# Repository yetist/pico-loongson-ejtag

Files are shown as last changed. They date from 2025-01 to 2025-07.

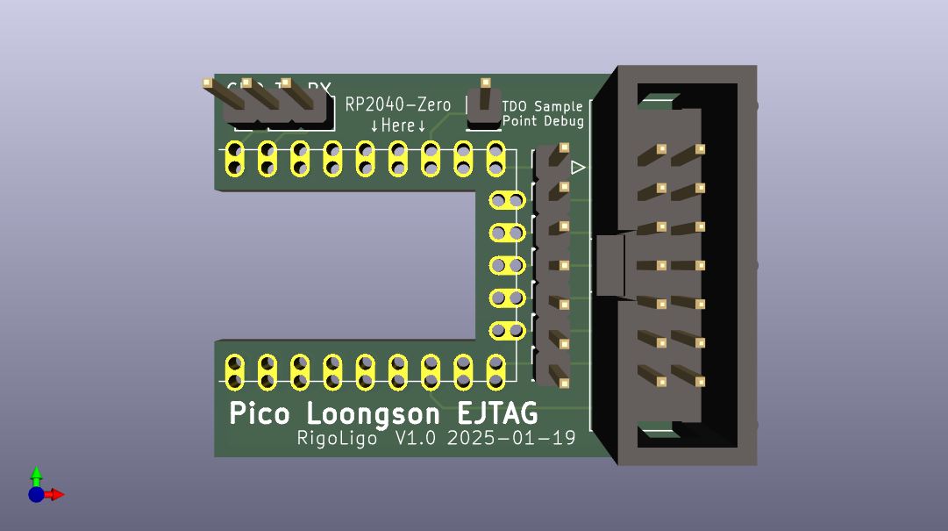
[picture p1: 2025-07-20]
hardware/lsejtag-rp2040zero-front.png

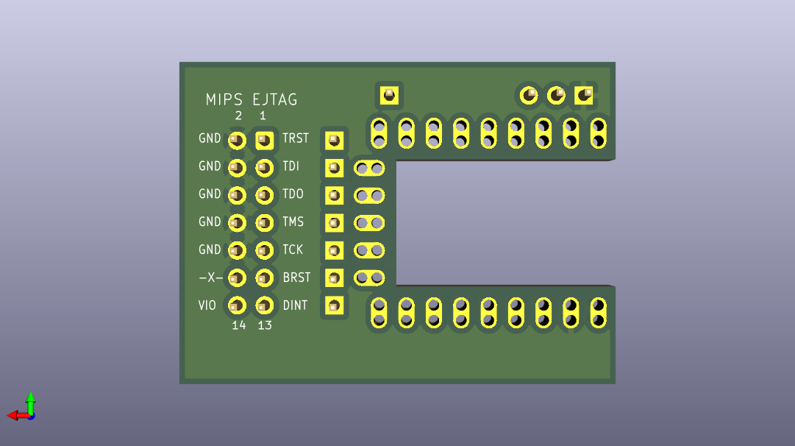
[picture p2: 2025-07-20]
hardware/lsejtag-rp2040zero-background.png

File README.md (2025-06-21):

# Pico Loongson EJTAG

[ENGLISH](README.en.md)

降成本版新款点这里 >> [CH32 Loongson EJTAG](https://github.com/RigoLigoRLC/ch32-loongson-ejtag)

欢迎加入！本项目专为龙芯嵌入式开发者爱好者打造，旨在重新实现龙芯官方EJTAG仿真器的核心功能，力求实现硬件功能完全对标且上位机软件兼容互通。

作为龙芯生态的共建者，我们深知龙芯3A6000等桌面级处理器性能比较亮眼，但其整机体积大、价格门槛高、与海外顶尖产品尚存差距的现状，让不少开发者望而却步（包括笔者本人）。而2K0300开发板的问世彻底改变了这一局面——这颗SoC不仅拥有媲美（超越）iMX6ULL等主流芯片的CoreMark性能，支持跑Linux/裸机，更以价格（百元级开发板）和小巧体积，为开发者打开了低成本进入LoongArch世界的通道。

然而，对于专注于裸机开发的嵌入式开发者而言，现有生态仍存在痛点：虽然2K0300可运行裸机程序，但官方调试工具高昂的售价成为了拦路虎。长期以来，龙芯的主要业务集中在桌面领域，对嵌入式生态投入有限（2K0300至今仅有第三方提供的残缺SDK，其IDE更是近乎讽刺地仅支持Windows平台）。我们希望通过这个项目证明：嵌入式开发者完全有能力为LoongArch的嵌入式开放生态开辟道路。

当前，固件基于逆向工程成果，主要参考对象为搭载20210129版本FPGA固件的官方调试工具和`la_dbg_tool_usb.exe`工具，并基于此独立实现了设备与上位机的通信协议、JTAG驱动。

## 功能完整度

当前版本还未完整实现所有命令的执行，会导致部分调试功能无法使用：

- 0xe，0xf：快速读内存指令

  将导致批量读取内存不可用

部分功能未完整验证，可能在部分机器上工作异常：

- 0xc，0xd：快速写内存指令

  未在 2K0300 以外的机器上测试，多核心处理器的适应性不明。仅在 2K0300 上测试了 SPI Flash 烧写功能。

## 实现方案

本固件基于树莓派RP2040-Zero开发板（成本极低，轻松复刻），具体引脚定义如下：

| RP2040 GPIO编号 | JTAG信号  | 备注 |
|---|---|-----|
| 8 | #TRST | |
| 9 | TDI | |
| 10 | TDO | |
| 11 | TMS | |
| 12 | TCK | |
| 13 | #BRST | |
| 14 | #DINT | |
| 26 | VIO | 模拟引脚 |

板载WS2812（GPIO16控制）作为状态指示灯，GPIO0/1上的UART0接口可输出开发调试信息。

- `src/lsejtag`与`inc/lsejtag`目录封装了与平台无关的核心逻辑（内部称其为`LS-EJTAG`协议栈，但并没有独立发布），负责处理上位机指令解析
- `src/ejtag_impl.c`包含硬件平台相关代码，移植至其他主控芯片时需重新实现

我们正在酝酿基于HPM5301主控的升级方案（硬件设计采用OSL-W-2.0协议开源，固件遵循GPL-3.0协议），重点是利用它的高速USB以图加快速度，敬请期待！

# 构建指南

我个人因为并不想安装体积比较大的SDK安装包，基于Windows环境手搓了构建流程，请按以下步骤配置开发环境：

## picotool安装
请将`picotool`完整安装至`C:\Program Files\CMake\picotool\`目录（内含CMake目标文件等必要组件）。`pioasm`工具也需同步安装。

**替代方案**：将安装目录路径添加至`CMAKE_PREFIX_PATH`环境变量，具体方式可依个人偏好选择。

## 环境配置
- `PICO_SDK_BASE`：设置为pico-sdk仓库的本地克隆路径（直接指向仓库根目录）
- `PICO_SDK_COMPILER_PATH`：指向MCU编译器所在目录（需包含`arm-none-eabi-gcc.exe`等可执行文件）

## VSCode编译流程
1. 通过Workspace Settings配置上述环境变量
2. 启动构建时选择"ARM GCC (Pico)"工具链
3. 正常情况下即可完成编译，若遇异常...祝君调试愉快

## clangd适配
因clangd/LLVM的设计缺陷（详见clangd/clangd#2289），需在clangd参数中添加：`--query-driver=.../your/gnu/toolchain/bin/arm-none-eabi-*.exe`以强制clangd识别GNU工具链路径（否则会误判为LLVM工具链导致头文件搜索失败）

# 许可

本项目除引用了其他项目有明确版权标识的文件之外，其他的代码均以 GPL-3.0-only 许可证发布。

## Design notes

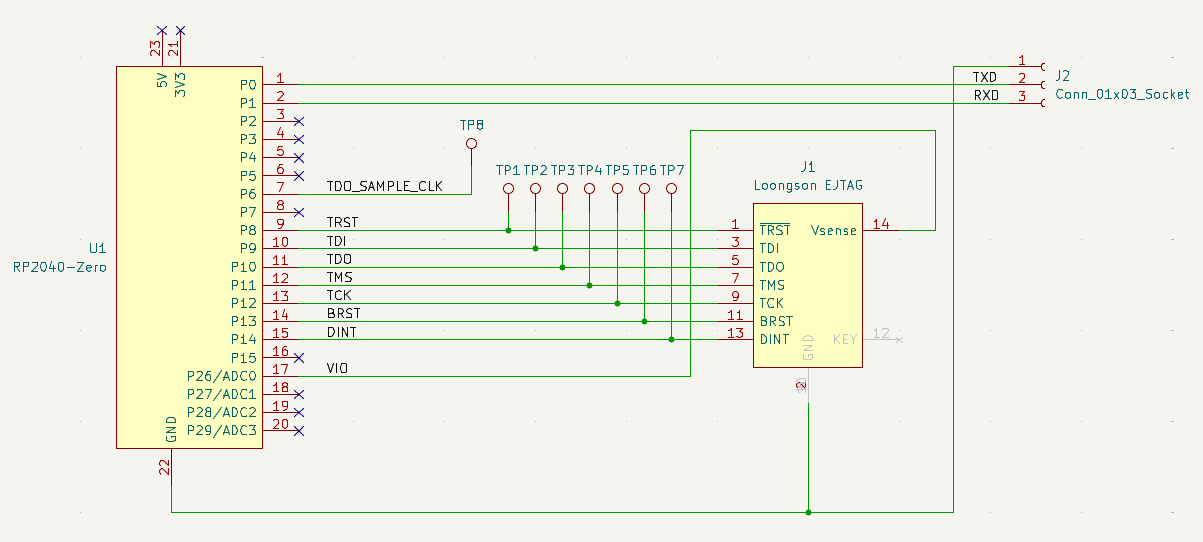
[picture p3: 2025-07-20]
hardware/lsejtag-rp2040zero-pcb.png

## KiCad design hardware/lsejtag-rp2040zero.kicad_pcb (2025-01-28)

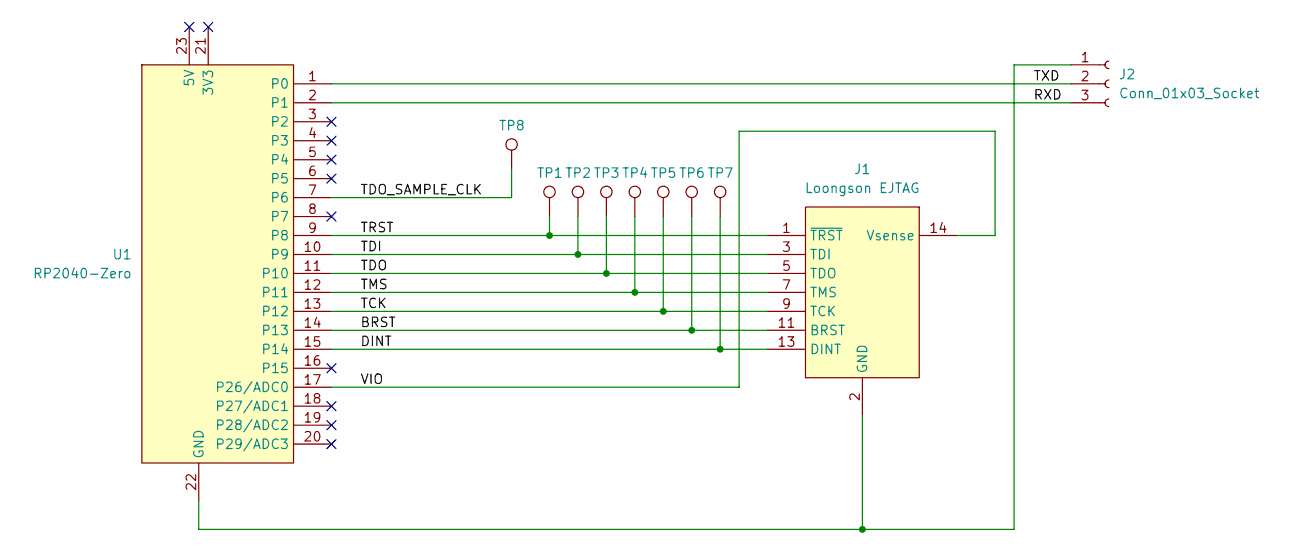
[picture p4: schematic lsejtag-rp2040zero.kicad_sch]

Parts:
J1: Loongson EJTAG; IDC-Header_2x07_P2.54mm_Vertical
J2: Conn_01x03_Socket; PinHeader_1x03_P2.54mm_Vertical
TP1, TP2, TP3, TP4, TP5, TP6, TP7, TP8: TestPoint; PinHeader_1x01_P2.54mm_Vertical
U1: RP2040-Zero

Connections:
/BRST: J1.11 (BRST), TP6.1, U1.14 (P13)
/DINT: J1.13 (DINT), TP7.1, U1.15 (P14)
/RXD: J2.3, U1.2 (P1)
/TCK: J1.9 (TCK), TP5.1, U1.13 (P12)
/TDI: J1.3 (TDI), TP2.1, U1.10 (P9)
/TDO: J1.5 (TDO), TP3.1, U1.11 (P10)
/TDO_SAMPLE_CLK: TP8.1, U1.7 (P6)
/TMS: J1.7 (TMS), TP4.1, U1.12 (P11)
/TRST: J1.1 (~TRST), TP1.1, U1.9 (P8)
/TXD: J2.2, U1.1 (P0)
/VIO: J1.14 (Vsense), U1.17 (P26/ADC0)
GND: J1.2 (GND), J1.4 (GND), J1.6 (GND), J1.8 (GND), J1.10 (GND), J2.1, U1.22 (GND)

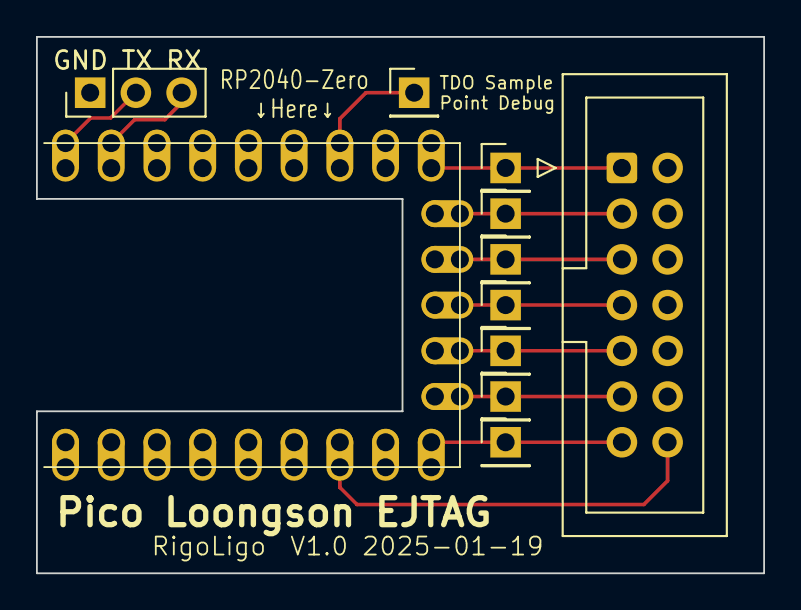
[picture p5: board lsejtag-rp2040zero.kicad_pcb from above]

Board: 2 copper layers, 40.4 x 29.8 mm, 11 parts (0 on the bottom side), 12 nets.

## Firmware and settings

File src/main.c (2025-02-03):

#include <pico/stdlib.h>
#include <hardware/uart.h>
#include <hardware/gpio.h>
#include <hardware/pio.h>
#include <hardware/dma.h>
#include <tusb.h>
#include <string.h>

#include "shell_port.h"
#include "lsejtag/lsejtag.h"
#include "config.h"
#include "ejtag.h"

#include "ejtag.pio.h"
#include "ws2812.pio.h"

lsejtag_ctx lsejtag_lib_ctx;
ejtag_impl_ctx ejtag_ctx;
Shell shell;
char shellBuffer[512];

void init_hardware();
void init_software();
void init_reset_tap_via_tms();
void init_print_clock();

void led_task();

int main() {
    init_hardware();
    init_software();
    init_reset_tap_via_tms();
    // init_print_clock();

    while (1) {
        tud_task();
        // shellTask(&shell);
        led_task();

        switch (lsejtag_dispatch(&lsejtag_lib_ctx)) {
        case dpr_execute:
            lsejtag_execute(&lsejtag_lib_ctx);
            break;
        case dpr_incomplete:
            break;
        case dpr_flush_tdo:
            lsejtag_flush_tdo(&lsejtag_lib_ctx);
            break;
        case dpr_run_jtag:
            lsejtag_run_jtag(&lsejtag_lib_ctx);
            break;
        case dpr_too_long:
            panic("LSEJTAG command too long");
        case dpr_unknown_cmd:
            break;
        case dpr_corrupt_state:
            printf("!!!!!! dpr_corrput_state !!!!!!\n");
            printf("cmd buf dump:\n");
            // dump_binary_to_console(ctx->buffered_cmd, sizeof(ctx->buffered_cmd));
            printf("buffered_length: %d\r", (int)lsejtag_lib_ctx.buffered_length);
            printf("wait_payload_size: %d\n", (int)lsejtag_lib_ctx.cmd_buf_wait_payload_size);
            printf("state: %d\n",lsejtag_lib_ctx.cmd_buf_state);
            panic("LSEJTAG corrupt state");
        case dpr_clean:
          break;
        }
    }
}

//==============================================================================
// Util
//==============================================================================

static inline uint32_t ws2812_rgb_u32(uint8_t r, uint8_t g, uint8_t b) {
    return
            ((uint32_t) (r) << 8) |
            ((uint32_t) (g) << 16) |
            (uint32_t) (b);
}

void isr_hardfault() {
    *ejtag_ctx.ws2812_write_addr = 0x10201000;
    stdio_puts_raw("!! HardFault !!\r\n");
    while (1);
}

//==============================================================================
// Other tasks
//==============================================================================

void led_task() {
    // LED illumination logic
    if (ejtag_ctx.led_turn_on) {
        ejtag_ctx.led_turn_on = 0;
        ejtag_ctx.led_timer_us = time_us_32();
        *ejtag_ctx.ws2812_write_addr = 0x10200000;
        return;
    }

    if (ejtag_ctx.led_timer_us == 0) {
        return;
    }

    // 300ms
    if (time_us_32() - ejtag_ctx.led_timer_us >= 300000) {
        *ejtag_ctx.ws2812_write_addr = 0x00200000;
        ejtag_ctx.led_timer_us = 0;
    }
}

//==============================================================================
// Initialization
//==============================================================================

void init_uart() {
    stdio_uart_init_full(uart0, 115200, 0, 1);

    printf("Pico Loongson EJTAG - By RigoLigo, FW Version " FIRMWARE_VERSION_STR "\n");
    printf("The Loongson EJTAG Probe reimplementation on RP2040.\n");
}

void init_gpio() {
    gpio_init(EJTAG_PIN_TRST);
    gpio_init(EJTAG_PIN_BRST);
    gpio_init(EJTAG_PIN_DINT);
    
    gpio_set_dir(EJTAG_PIN_TRST, true);
    gpio_set_dir(EJTAG_PIN_BRST, true);
    gpio_set_dir(EJTAG_PIN_DINT, true);

    gpio_set_pulls(EJTAG_PIN_TRST, true, false);
    gpio_set_pulls(EJTAG_PIN_BRST, true, false);
    gpio_set_pulls(EJTAG_PIN_DINT, true, false);

    gpio_put(EJTAG_PIN_TRST, true);
    gpio_put(EJTAG_PIN_BRST, true);
    gpio_put(EJTAG_PIN_DINT, true);
}

void init_pio() {
    pio_sm_config smcfg = pio_get_default_sm_config();
    static const char panic_text[] = "%s PIO SM allocation failed. This should not happen.";

    // TDI/TMS SM program
    if (pio_add_program_at_offset(pio0, &ejtag_tdi_program, SM_PC_TDI) < 0) {
        panic(panic_text, "TDI");
    }
    if (pio_add_program_at_offset(pio0, &ejtag_tms_program, SM_PC_TMS) < 0) {
        panic(panic_text, "TMS");
    }
    if (pio_add_program_at_offset(pio0, &ejtag_tdo_program, SM_PC_TDO) < 0) {
        panic(panic_text, "TDO");
    }
    if (pio_add_program_at_offset(pio0, &ws2812_program, SM_PC_WS2812) < 0) {
        panic(panic_text, "WS2812");
    }

    // EJTAG GPIO alternative function selection
    pio_gpio_init(pio0, EJTAG_PIN_TDI);
    pio_gpio_init(pio0, EJTAG_PIN_TDO);
    pio_gpio_init(pio0, EJTAG_PIN_TCK);
    pio_gpio_init(pio0, EJTAG_PIN_TMS);
    pio_gpio_init(pio0, EJTAG_PIN_BRST); // TODO:REMOVE
    pio_gpio_init(pio0, EJTAG_PIN_TDO_SAMPLE_TIME);

    // TDI SM config
    pio_sm_set_consecutive_pindirs(pio0, SM_TDI, EJTAG_PIN_TDI, 1, true);
    pio_sm_set_consecutive_pindirs(pio0, SM_TDI, EJTAG_PIN_TCK, 1, true);
    pio_sm_set_consecutive_pindirs(pio0, SM_TDI, EJTAG_PIN_BRST, 1, true);
    sm_config_set_fifo_join(&smcfg, PIO_FIFO_JOIN_TX);
    sm_config_set_out_pins(&smcfg, EJTAG_PIN_TDI, 1);
    sm_config_set_out_shift(&smcfg, true, false, 0);
    sm_config_set_sideset_pins(&smcfg, EJTAG_PIN_BRST); // TODO:REMOVE
    sm_config_set_sideset(&smcfg, 1, false, false); // TODO:REMOVE
    sm_config_set_wrap(&smcfg, ejtag_tdi_wrap_target + SM_PC_TDI, ejtag_tdi_wrap + SM_PC_TDI);
    sm_config_set_clkdiv(&smcfg, 6.f);
    pio_sm_init(pio0, SM_TDI, SM_PC_TDI, &smcfg);
    ejtag_ctx.tdi_write_addr = &pio0->txf[SM_TDI];

    // TDI SM IRQ (IRQ bit 0, this is for TDI&TMS completion handler since they are in sync)
    irq_set_exclusive_handler(PIO0_IRQ_0, isr_pio0_irq0);
    pio_set_irq0_source_enabled(pio0, pis_interrupt0, true);
    irq_set_enabled(PIO0_IRQ_0, true);

    // TMS SM config
    pio_sm_set_consecutive_pindirs(pio0, SM_TMS, EJTAG_PIN_TMS, 1, true);
    sm_config_set_out_pins(&smcfg, EJTAG_PIN_TMS, 1);
    sm_config_set_sideset_pins(&smcfg, EJTAG_PIN_TCK);
    sm_config_set_sideset(&smcfg, 1, false, false);
    sm_config_set_wrap(&smcfg, ejtag_tms_wrap_target + SM_PC_TMS, ejtag_tms_wrap + SM_PC_TMS);
    pio_sm_init(pio0, SM_TMS, SM_PC_TMS, &smcfg);
    ejtag_ctx.tms_write_addr = &pio0->txf[SM_TMS];

    // TDO SM (PIO0, SM2) config
    pio_sm_set_consecutive_pindirs(pio0, SM_TDO, EJTAG_PIN_TDO, 1, false);
    pio_sm_set_consecutive_pindirs(pio0, SM_TDO, EJTAG_PIN_TDO_SAMPLE_TIME, 1, true);
    sm_config_set_fifo_join(&smcfg, PIO_FIFO_JOIN_NONE);
    sm_config_set_sideset_pins(&smcfg, EJTAG_PIN_TDO_SAMPLE_TIME);
    sm_config_set_in_pins(&smcfg, EJTAG_PIN_TDO);
    sm_config_set_wrap(&smcfg, ejtag_tdo_wrap_target + SM_PC_TDO, ejtag_tdo_wrap + SM_PC_TDO);
    pio_sm_init(pio0, SM_TDO, SM_PC_TDO, &smcfg);
    ejtag_ctx.tdo_write_addr = &pio0->txf[SM_TDO];
    ejtag_ctx.tdo_read_addr = &pio0->rxf[SM_TDO];

    // WS2812 SM (PIO0, SM3) config
    ws2812_program_init(pio0, SM_WS2812, SM_PC_WS2812, WS2812_PIN, 800000, false);
    ejtag_ctx.ws2812_write_addr = &pio0->txf[SM_WS2812];
}

void init_dma() {
    dma_channel_config cfg;

    ejtag_ctx.tdi_chan = dma_claim_unused_channel(true);
    cfg = dma_channel_get_default_config(ejtag_ctx.tdi_chan);
    channel_config_set_transfer_data_size(&cfg, DMA_SIZE_32);
    channel_config_set_read_increment(&cfg, true);
    channel_config_set_write_increment(&cfg, false);
    channel_config_set_dreq(&cfg, DREQ_PIO0_TX0 + SM_TDI);
    dma_channel_configure(ejtag_ctx.tdi_chan, &cfg, ejtag_ctx.tdi_write_addr, NULL, 0, false);

    ejtag_ctx.tms_chan = dma_claim_unused_channel(true);
    channel_config_set_dreq(&cfg, DREQ_PIO0_TX0 + SM_TMS);
    channel_config_set_chain_to(&cfg, ejtag_ctx.tms_chan);
    dma_channel_configure(ejtag_ctx.tms_chan, &cfg, ejtag_ctx.tms_write_addr, NULL, 0, false);

    ejtag_ctx.tdo_chan = dma_claim_unused_channel(true);
    channel_config_set_read_increment(&cfg, false);
    channel_config_set_write_increment(&cfg, true);
    channel_config_set_dreq(&cfg, DREQ_PIO0_RX0 + SM_TDO);
    channel_config_set_chain_to(&cfg, ejtag_ctx.tdo_chan);
    dma_channel_configure(ejtag_ctx.tdo_chan, &cfg, NULL, ejtag_ctx.tdo_read_addr, 0, false);

    ejtag_ctx.dma_start_mask_no_tdo = (1 << ejtag_ctx.tdi_chan) | (1 << ejtag_ctx.tms_chan);
    ejtag_ctx.dma_start_mask = (1 << ejtag_ctx.tdo_chan) | ejtag_ctx.dma_start_mask_no_tdo;

    // Interrupts
    dma_channel_set_irq0_enabled(ejtag_ctx.tdi_chan, true);
    dma_channel_set_irq0_enabled(ejtag_ctx.tms_chan, true);
    dma_channel_set_irq1_enabled(ejtag_ctx.tdo_chan, true);

    irq_set_exclusive_handler(DMA_IRQ_0, isr_dma_irq0);
    irq_set_exclusive_handler(DMA_IRQ_1, isr_dma_irq1);
    irq_set_enabled(DMA_IRQ_0, true);
    irq_set_enabled(DMA_IRQ_1, true);
}

void init_hardware() {
    init_uart();
    init_gpio();
    init_pio();
    init_dma();
}

void init_task_context() {
    // LED task
    ejtag_ctx.led_timer_us = 0;
    ejtag_ctx.led_turn_on = 0;
    // Make red LED illuminate
    *ejtag_ctx.ws2812_write_addr = 0x00200000;
}

void init_software() {
    lsejtag_init_ctx(&lsejtag_lib_ctx);
    tud_init(BOARD_TUD_RHPORT);
    init_task_context();

    // shell.write = shell_port_write_usb;
    // // shell.read = shell_port_read_usb;
    // shellInit(&shell, shellBuffer, sizeof(shellBuffer));
}

void init_reset_tap_via_tms() {
    *ejtag_ctx.tms_write_addr = 31;
    *ejtag_ctx.tms_write_addr = 0x0FFFFFFF;
    pio_set_sm_mask_enabled(pio0, SM_MASK_TDI_TMS, true);
    sleep_ms(5); // This is more than enough!
    pio_set_sm_mask_enabled(pio0, SM_MASK_JTAG, false);
}

void init_print_clock() {
    uint f_pll_sys = frequency_count_khz(CLOCKS_FC0_SRC_VALUE_PLL_SYS_CLKSRC_PRIMARY);
    uint f_pll_usb = frequency_count_khz(CLOCKS_FC0_SRC_VALUE_PLL_USB_CLKSRC_PRIMARY);
    uint f_rosc = frequency_count_khz(CLOCKS_FC0_SRC_VALUE_ROSC_CLKSRC);
    uint f_clk_sys = frequency_count_khz(CLOCKS_FC0_SRC_VALUE_CLK_SYS);
    uint f_clk_peri = frequency_count_khz(CLOCKS_FC0_SRC_VALUE_CLK_PERI);
    uint f_clk_usb = frequency_count_khz(CLOCKS_FC0_SRC_VALUE_CLK_USB);
    uint f_clk_adc = frequency_count_khz(CLOCKS_FC0_SRC_VALUE_CLK_ADC);

    puts("Clocks debug:");
    printf("pll_sys  = %dkHz\n", f_pll_sys);
    printf("pll_usb  = %dkHz\n", f_pll_usb);
    printf("rosc     = %dkHz\n", f_rosc);
    printf("clk_sys  = %dkHz\n", f_clk_sys);
    printf("clk_peri = %dkHz\n", f_clk_peri);
    printf("clk_usb  = %dkHz\n", f_clk_usb);
    printf("clk_adc  = %dkHz\n", f_clk_adc);
}

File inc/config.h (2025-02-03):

#pragma once

#define DISABLE_DBGPRINT

#ifndef FIRMWARE_VERSION_STR
#define FIRMWARE_VERSION_STR            "0.2.0"
#endif

#ifndef DISABLE_DBGPRINT
#define DbgPrint printf
#else
#define DbgPrint(...)
#endif

#define EJTAG_PIN_TRST                  8
#define EJTAG_PIN_TDI                   9
#define EJTAG_PIN_TDO                   10
#define EJTAG_PIN_TMS                   11
#define EJTAG_PIN_TCK                   12
#define EJTAG_PIN_BRST                  13
#define EJTAG_PIN_DINT                  14
#define EJTAG_PIN_VIO                   26
#define EJTAG_PIN_TDO_SAMPLE_TIME       6

#define EJTAG_SM_START_MASK             0x7
#define EJTAG_SM_START_MASK_NO_TDO      0x3

#define WS2812_PIN                      16

// PIO allocation
#define SM_TDI                                  0
#define SM_TMS                                  1
#define SM_TDO                                  2
#define SM_WS2812                               3

#define SM_MASK_TDI_TMS                         ((1<<(SM_TDI))|(1<<(SM_TMS)))
#define SM_MASK_JTAG                            (SM_MASK_TDI_TMS|(1<<(SM_TDO)))

// PIO program location
#define SM_PC_TDI                               8
#define SM_PC_TMS                               16
#define SM_PC_TDO                               24
#define SM_PC_WS2812                            0

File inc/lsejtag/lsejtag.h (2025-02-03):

#pragma once

#include <stdint.h>
#include <stdlib.h>
#include <stdbool.h>

#include "cmd_headers.h"

// INTERNAL USE.
typedef enum {
    op_probe_mem_rw                     = 0x01,
    op_io_manip                         = 0x03,
    op_ir_rw                            = 0x04,
    op_dr_rw                            = 0x05,
    op_loopback_test                    = 0x08,
    op_fast_target_mem_write_fastdata   = 0x0c,
    op_fast_target_mem_write            = 0x0d,
    op_fast_target_mem_read_fastdata    = 0x0e,
    op_fast_target_mem_read             = 0x0f,
    op_get_firmware_date                = 0x1f,
} lsejtag_cmd_op;

// INTERNAL USE.
typedef enum {
    io_led,                 // Green LED. Default to low.
    io_fpga_reset,          // Non-used.
    io_oe,                  // JTAG output enable. When OE is low output is enabled. Default to low.
    io_trst,                // TRST pin. Default to high.
    io_brst,                // BRST pin. Default to high.
    io_dint,                // DINT pin. Default to high.
    io_tap_reset,           // Non-used.
    io_maximum,
} lsejtag_io;

// INTERNAL USE.
typedef struct {
    union {
        uint16_t u16;
        lsejtag_cmd_header_common common;
        lsejtag_cmd_header_probe_mem_rw probe_mem_rw;
        lsejtag_cmd_header_io_manip io_manip;
        lsejtag_cmd_header_ir_rw ir_rw;
        lsejtag_cmd_header_dr_rw dr_rw;
        lsejtag_cmd_header_loopback_test loopback_test;
        lsejtag_cmd_header_fast_target_mem_write fast_target_mem_write;
        lsejtag_cmd_header_fast_target_mem_read fast_target_mem_read;
    };
} lsejtag_cmd_header;

// INTERNAL USE.
typedef struct {
    union {
        lsejtag_cmd_common common;
        lsejtag_cmd_probe_mem_rw probe_mem_rw;
        lsejtag_cmd_io_manip io_manip;
        lsejtag_cmd_ir_rw ir_rw;
        lsejtag_cmd_dr_rw dr_rw;
        lsejtag_cmd_loopback_test loopback_test;
        lsejtag_cmd_fast_target_mem_write_at_core fast_mem_write_at_core;
        lsejtag_cmd_fast_target_mem_write fast_mem_write;
        lsejtag_cmd_fast_target_mem_read_at_core fast_mem_read_at_core;
    };
} lsejtag_cmd;

// INTERNAL USE. Command buffering state machine state.
typedef enum {
    cbs_clean,          // The buffer is clean, no pending commands
    cbs_wait_header,    // Pending command has only 1 byte available, command header is incomplete
    cbs_wait_cfg,       // Pending command's header is available, but config section is incomplete
    cbs_wait_payload,   // Pending command's header and config section is available, but payload
                        // is incomplete. In this case, `cmd_buf_wait_payload_size` represents how
                        // many bytes of payload data is yet to be read.
    cbs_execute,        // The buffer contains a valid command and awaits execution.
} lsejtag_cmd_buf_state;

typedef enum {
    dpr_execute,        // A command was successfully fetched, call `lsejtag_exec_cmd` immediately.
    dpr_clean,          // Command buffer and user provided USB RX FIFO are both empty. This result
                        // indicates a clean end state.
    dpr_incomplete,     // An incomplete command was fetched and buffered. User USB RX FIFO is
                        // exhausted.
    dpr_flush_tdo,      // User should call `lsejtag_flush_tdo` immediately to flush TDO. This code
                        // does not imply any status of command buffer; `lsejtag_dispatch` must be
                        // called again immediately after flushing TDO buffer to find out current
                        // status of command buffer.
    dpr_run_jtag,       // A prepared JTAG buffer is available and user must call `lsejtag_run_jtag`
                        // to start an JTAG transaction. This is usually returned after a successful
                        // JTAG command was executed.
    dpr_too_long,       // An excessively long command was found and was too large to fit in scratch
                        // buffer. This is a fatal error. Notice that this error is not emitted for
                        // `op_fast_target_mem_write*` ops, since this op really do deal with large
                        // amount of data. Special continuation logic is implemented for this op
                        // to make it work across multiple `lsejtag_execute` calls.
    dpr_unknown_cmd,    // An unknown command was found. This may be emitted after command header
                        // was read. Ignore this error.
    dpr_corrupt_state,  // An invalid cmd_buf_state was found. This is a fatal error.
} lsejtag_dispatch_result;

typedef enum {
    cer_success,        // Command executed successfully. This does not imply peripheral state (like
                        // JTAG controller). When dispatch routine is called again, user might get a
                        // useful instruction about what to do with other peripherals, like USB and
                        // JTAG controller.
    cer_continue,       // Command was partially executed, because more data has to be sent to/
                        // received from the host. This is a special return code for
                        // fast_target_mem_read/write ops. When this code was returned, buffer state
                        // is not cleared to cbs_clean, and command continuation context info will
                        // be filled in preparation to next stage of execution.
    cer_await_jtag_buf, // Command was not executed because JTAG I/O buffer is full. There are two
                        // JTAG buffers, and a JTAG related command may execute when any of them is
                        // free. But when both buffer blocks are full, this error is emitted.
    cer_await_usb_tx,   // Command was not executed because USB TX FIFO is full. This is only
                        // emitted when a command that requires immediate access to USB TX FIFO
                        // (like probe memory RW, or firmware version read) is executed. When USB TX
                        // FIFO is full but a JTAG buffer is free, JTAG related commands still may
                        // execute, their USB TX FIFO check happens 
    cer_not_ready,      // Command was not executed because command buffer state is not ready.
    cer_bad_continue,   // Continuation context was valid for a command that does not support
                        // continuation. This is a fatal error.
} lsejtag_cmd_exec_result;
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

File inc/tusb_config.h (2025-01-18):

/*
 * The MIT License (MIT)
 *
 * Copyright (c) 2019 Ha Thach (tinyusb.org)
 *
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
 */

#ifndef _TUSB_CONFIG_H_
#define _TUSB_CONFIG_H_

#ifdef __cplusplus
 extern "C" {
#endif

//--------------------------------------------------------------------+
// Board Specific Configuration
//--------------------------------------------------------------------+

// RHPort number used for device can be defined by board.mk, default to port 0
#ifndef BOARD_TUD_RHPORT
#define BOARD_TUD_RHPORT      0
#endif

// RHPort max operational speed can defined by board.mk
#ifndef BOARD_TUD_MAX_SPEED
#define BOARD_TUD_MAX_SPEED   OPT_MODE_DEFAULT_SPEED
#endif

//--------------------------------------------------------------------
// COMMON CONFIGURATION
//--------------------------------------------------------------------

// defined by compiler flags for flexibility
#ifndef CFG_TUSB_MCU
#error CFG_TUSB_MCU must be defined
#endif

#ifndef CFG_TUSB_OS
#define CFG_TUSB_OS           OPT_OS_NONE
#endif

#ifndef CFG_TUSB_DEBUG
#define CFG_TUSB_DEBUG        0
#endif

// Enable Device stack
#define CFG_TUD_ENABLED       1

// Default is max speed that hardware controller could support with on-chip PHY
#define CFG_TUD_MAX_SPEED     BOARD_TUD_MAX_SPEED

/* USB DMA on some MCUs can only access a specific SRAM region with restriction on alignment.
 * Tinyusb use follows macros to declare transferring memory so that they can be put
 * into those specific section.
 * e.g
 * - CFG_TUSB_MEM SECTION : __attribute__ (( section(".usb_ram") ))
 * - CFG_TUSB_MEM_ALIGN   : __attribute__ ((aligned(4)))
 */
#ifndef CFG_TUSB_MEM_SECTION
#define CFG_TUSB_MEM_SECTION
#endif

#ifndef CFG_TUSB_MEM_ALIGN
#define CFG_TUSB_MEM_ALIGN          __attribute__ ((aligned(4)))
#endif

//--------------------------------------------------------------------
// DEVICE CONFIGURATION
//--------------------------------------------------------------------

#ifndef CFG_TUD_ENDPOINT0_SIZE
#define CFG_TUD_ENDPOINT0_SIZE    64
#endif

//------------- CLASS -------------//
#define CFG_TUD_HID               0
#define CFG_TUD_CDC               1
#define CFG_TUD_MSC               0
#define CFG_TUD_MIDI              0
#define CFG_TUD_VENDOR            1

// CDC FIFO size of TX and RX
#define CFG_TUD_CDC_RX_BUFSIZE    (TUD_OPT_HIGH_SPEED ? 512 : 64)
#define CFG_TUD_CDC_TX_BUFSIZE    (TUD_OPT_HIGH_SPEED ? 512 : 64)

// Vendor FIFO size of TX and RX
#define CFG_TUD_VENDOR_RX_BUFSIZE (TUD_OPT_HIGH_SPEED ? 512 : 64)
#define CFG_TUD_VENDOR_TX_BUFSIZE (TUD_OPT_HIGH_SPEED ? 512 : 64)

#ifdef __cplusplus
 }
#endif

#endif /* _TUSB_CONFIG_H_ */

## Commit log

2025-01-28 feat: PCB design
    [lsejtag-rp2040zero.kicad_pcb, lsejtag-rp2040zero.kicad_sch]
2025-07-20 add pcb
